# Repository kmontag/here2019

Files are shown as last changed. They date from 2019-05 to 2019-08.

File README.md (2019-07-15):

## Usage

See `featherstream/README.md` and `kontrol/README.md` for usage
overviews of the two main devices.

## Assembly

In addition to the build instructions in `featherstream/README.md` and
`kontrol/README.md`:
  
### DotStar strip

- Compile and print `things/dot_star_endcap.scad`.
- Cut the strip (https://www.adafruit.com/product/2237) to
  the desired number of LEDs along the midpoint of the metal contacts.
- Input side:
  - Run the female end of a 4-wire cable set
    (https://www.adafruit.com/product/744) through the large endcap
    fitting, with the free wire ends coming out of the larger end.
  - Run the wires through the 4 holes in the smaller endcap
    fitting. Check your strip to see the positions of the DI/CI
    contacts, and order the wires such that:
    - Red goes to VOC (+5V)
    - White goes to CI
    - Yellow goes to DI
    - Black goes to GND
  - Solder the wires to the contacts
  - Test the connection by connecting to an assembled feather
  - Put some hot glue or superglue onto the soldered connections for
    extra security.
  - Slide the smaller endcap over the strip, and place an M3 nut
    (https://www.amazon.com/dp/B07JD4ZLFT/) into the receptacle.
  - Put some hot glue or superglue on the outside of the endcap where
    the wires enter.
  - Wrap a bunch of electric tape around the 4-wire cable, between the
    large endcap and the strip. The goal is to reduce strain on the
    soldered connections once the endcap is fastened, so position it
    such that it forces a little bit of slack in the wires when the
    large endcap slides all the way up.
  - Slide the large endcap over the small one, and screw an M3 screw
    (https://www.amazon.com/dp/B01LZYC586/) through the hole, into the
    nut, and down far enough that it presses agains the strip pretty
    hard. The goal is to hold the endcap in place without placing
    strain on the soldered connections.
- Output side:
  - If chaining strips together, this is the same as the input side
    except:
    - Use the male side of the 4-wire cable instead of the female.
    - Make sure you place the over-screw onto the 4-wire cable before
      soldering.
    - Make sure you're soldering to the CO/DO side of the contacts (not CI/DI).
  - If not chaning strips together, you can just seal this off with
    the smaller endcap piece or some shrink wrap / tape.
    
## Development - running a local `featherstreamer` server

`featherstreamer` is what the Pis run to serve pixels to feathers. There are two components:

### `featherstreamer`

This is the main data server. Before running it:

- Place any video files you want to stream in
  `kontrol/media-src/`. These can be anything readable by `ffmpeg`.
- Run `make media` to compile the files into raw pixel data that can
  be streamed without processing overhead. The built files live in
  `kontrol/media-build/`.
- Run `make` in `kontrol/`.

To run the program, in `kontrol/featherstreamer`:

``` bash
npm start
```

You can also use `npm run start-dev` during development, to pick up
changes to source files automatically.

To get a Feather to see your local `featherstreamer` server, you'll
need to make compile-time changes. In your `secrets.h`, place the
following:

``` c++
#define SECRET_PAIRED_SSID "Your home SSID"
#define SECRET_PAIRED_PASSPHRASE "Your WiFi password"
#define SECRET_SERVER_IP IPAddress(192, 168, 0, 1) // Or whatever your computer's local IP address is
```

And then compile and upload to your Feather.

### `featherstreamer-web`

This is the web interface that's normally accessible at
http://192.168.8.1 on a Feather's hosted network. It shows details
about connected devices, and allows you to simulate interactions with
the hardware.

Before starting, run `make` in `kontrol/`. Then start the server with
`npm start` in `kontrol/featherstreamer-web`. The page should open
automatically in your browser; if not, it's accessible at
http://localhost:3000.

Note the UI won't be functional unless the `featherstreamer` server is
also running locally.

## Development dependencies

- PlatformIO for building the feather software: `brew install platformio`
- OpenSCAD for building 3D-printable objects: `brew cask install openscad`
- Ansible for configuring a Pi: `brew install ansible`
- Node/NPM for running the `featherstreamer` server (the thing the Pi
  uses to stream video) locally

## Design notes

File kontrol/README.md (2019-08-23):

This directory contains config and software for a Pi Zero W to:
- run a `featherstreamer` server (and web UI) for `featherstream`
  devices to connect to
- host a local WiFi access point, and connect to (or host) a "master"
  access point when in slave (or master) mode

### Usage overview

This device has an on/off switch, a USB port, an SD card slot, and a
rotary encoder.

The USB port is used to charge the battery (and can power the device
at the same time).

The SD card slot holds the card that runs the Pi.

The on/off switch is an on/off switch.

The rotary encoder is the main controller for the device. Any
contiguous turn in one direcion is processed as a single clockwise or
counter-clockwise "step" - the notches in the encoder don't really
matter. Turn it to cycle through videos. Press it (without turning it)
to toggle connected LEDs on or off.

To change modes, press and hold then encoder for more than 1s, then release it and quickly press it one or more times to select the mode:

- 1 click for isolated mode
- 2 clicks for slave mode
- 3 clicks for master mode
- 4 clicks for pairing mode

Once the device is booted up, you should be able to see a WiFi network
called `featherstreamer-[something]`. That's your device's personal
access point. By default, the password for this network (and all
others) is `feath3rstr`. The device normally lives at
http://192.168.8.1, or http://192.168.9.1 when in master mode.

### Runtime configuration

Connect to the pi's access point and go to http://192.168.8.1 (or
http://192.168.9.1 if the device is in `master` mode) to see a
configuration UI. 

Once a feather is connected, you'll be able to set the channel that
should be streamed to it, the brightness, and the persistent color of
its offline animation.

You can also see some debug info about the device, and simulate
interactions with the rotary encoder.

### Assembly

- First, run the software setup instructions below and make sure your
  unmodified Pi Zero W (https://www.adafruit.com/product/3400) is
  working. During setup, you can power it from the USB port farthest
  from the SD card.
- Get a rotary encoder (https://www.adafruit.com/product/377) and
  solder a short wire between one of the push-switch pins (i.e. either
  pin on the side with two pins) and the middle (common) pin on the
  other side. This allows us to share the ground connection for the
  rotary encoder and the push button.
- Solder a chunk of headers "upside down" (i.e. with the plastic nub
  on the bottom of the chip) to the last 4 pins (i.e. on the side
  furthest from the SD card) of the outer row of the Pi. These pins,
  in order moving away from the SD card, are Ground, GPIO 16, GPIO 20,
  and GPIO 21. Solder ~5cm wires to all of the pins, and slide shrink
  wrap down to secure the connections.
- Solder the wires from the headers to these pins on the rotary encoder:
  - Ground (innermost pin with headers) to Common (middle pin on the encoder side)
  - GPIO16 to rotary pin B (right pin on the encoder side)
  - GPIO20 to rotary pin A (left pin on the encoder side)
  - GPIO21 to the remaining push switch pin
  Make sure to secure the connections with shrink wrap.
- Solder a SPDT slide switch (https://www.adafruit.com/product/805) to
  the Vs, EN, and GND pins of a PowerBoost 1000 charger
  (https://www.adafruit.com/product/2465).
- Solder a 2-pin chunk of headers to the G and 5V pins on the
  PowerBoost. Orient the headers upside-down as with the Pi.
- Solder another 2-pin chunk of headers (again upside-down) to the 2nd
  and 3rd pins on the outer row of the Pi. These are 5V and G,
  respectively.
- Solder ~3cm wires to connect the +5V and G pins of the PowerBoost to
  the Pi.
- Solder a ~1kOhm resistor in series with one leg of an LED, as
  described in the featherstream assembly instructions.
- Cover the resistor legs with shrink wrap. Solder the positive end to
  the Pi's GPIO11 (12th pin on the inner row as you move away from the
  SD card) and G (easiest option is the 13th pin on the inner row as
  you move away from the SD card). Bend the LED legs so it lays across
  the Pi and reaches near the USB ports.
- Connect a 2000mAh LiPo battery
  (https://www.adafruit.com/product/2011) to the PowerBoost.  Do this
  **before** plugging into the PowerBoost's USB port, otherwise you
  may damage the board.
- Plug USB power into the PowerBoost (make sure you're not also
  plugged into the Pi's onboard USB power port). You should see an
  orange light to indicate the battery is charging. If the switch is
  in the ON position, you'll also see a blue light to indicate that
  power is being provided at the 5V pin.
- Test your circuit. With the PowerBoost plugged in and/or the battery
  charged, flip the switch on. You should see:
  - the green onboard LED light up immediately
  - after a few minutes, the installed LED blinking once every ~3s to
    indicate that the server has started and is running in isolated
    mode
    
  To test that the rotary encoder is properly connected, turn it two
  clicks (not rotary notches - see above) while pressing it to place
  the device in slave mode. The LED should then start blinking twice
  every 3s, instead of once.

- Print `../things/pi_box.scad` and put everything inside. The easiest
  order to place things is probaby:
  - PowerBoost placed against the wall opposite the `HERE` text, with
    its switch seated in the small hole and its USB port accessible
    through the back wall. If you want, you can use an M2.5 screw/nut
    to hold the chip in place - seat the nut behind the little post
    with a hole in it near the back of the chip, and run the screw
    through the nearby hole in the chip and into the nut. This isn't
    strictly necessary, but will make it easier to maintain the right
    position while putting the lid on the box.
    
    Note you should leave the battery attached to the PowerBoost - the
    wires should run under the board and behind it, so you can drop
    the battery into the other side of the box once everything else is
    in place.
  - Pi placed in its seat in the middle of the box. The SD card needs
    to be removed before you put the Pi in. It should sit so that the
    USB ports are flush with the top of the box.
  - Rotary encoder placed through the hole opposite the PowerBoost USB
    port, with the square base rotated so that it sits neatly on the
    nearby shelf (i.e. so the soldered pins are on the sides of the
    box, not the top and bottom). **Make sure you put the washer on
    before pushing the encoder through the hole.**
    
    This part can be tricky, be careful not to break any connections -
    if everything is well-soldered and supported with shrink wrap, it
    should be pretty stable. Once the encoder is propertly seated,
    there shouldn't be much strain on any of the soldered connections.
  - Battery placed in the remaining space near the wall with the
    `HERE` text.
- Secure the rotary encoder with the nut that came with it, and attach
  the plastic cap.
- Put the SD card back in the Pi through the box wall and test the
  circuit again to make sure everything's still intact after
  insertion.
- Place M3 nuts (https://www.amazon.com/dp/B07JD4ZLFT) in the two
  holders on the box lid.
- Place the lid and secure it with M3 screws
  (https://www.amazon.com/dp/B01LZYC586).
    
### Media setup

Push videos to the device using `make deploy-media` while connected to
the device's access point.

Config for your lights should get added to `frameplayer.conf.js` in
this directory. Each `featherstream` device receives pixel data for
one channel (you can configure this in the Pi's web UI). For each of
your `featherstream` devices, add a channel with a descriptive name to
`frameplayer.conf.js`, set a height and width to scale video files
before sampling pixels, and then provide a list of pixels (as x/y
coordinates) to sample. Data from these pixels will get sent (in this
order) to your LED strip(s).

Commit any changes to `frameplayer.conf.js`, so that when you're
receiving data from someone else in master mode, you'll get correctly
positioned pixel data on your setup.

### Setup from a distributed image

If you won't be doing any development, you can just burn the image to
an SD card and boot the pi - everything is already installed.

Then put the device into pairing mode (four clockwise clicks while
pressing the rotary encoder), put one or more feathers into pairing
mode (flip the switch repeatedly at boot), and wait for the light on
the feathers to start blinking quickly.

Optionally, in the `boot` volume that mounts when you insert the SD
card into your laptop:

- edit the `reset` file with a custom SSID for your device.
- create a file called `wpa_supplicant.conf` (see the example in this
  directory) containing your home WiFi credentials, to make the device
  connect to your network when it's in `master` or `pairing` mode.

These optional steps can be performed at any time.

### From-scratch Pi setup

- Download the latest Raspbian lite:
  <https://www.raspberrypi.org/downloads/raspbian/>.

- Install onto SD card with Etcher or similar:
  <https://www.raspberrypi.org/documentation/installation/installing-images/README.md>.

- Mount the `boot` partition (i.e. just reinsert the drive) and
  perform preliminary setup:
  
``` shell
$ make boot
```

- Put the SD card into the Pi and boot.

- If you want, test SSH (default password is `raspberry`):

``` shell
$ ssh -o StrictHostKeyChecking=no -o GlobalKnownHostsFile=/dev/null -o UserKnownHostsFile=/dev/null pi@raspberrypi.local
```

- Perform initial hostname/credentials setup. This will also generate
  an SSH key pair in [`ansible/local`](ansible/local) if necessary,
  which will be shared for all future devices. Ansible must be
  installed.

``` shell
$ make bootstrap
```

- Perform all additional provisioning to set up the node. Add the
  outputted hostname from the previous step to
  `ansible/inventory/hosts.local` (create the file if it doesn't
  exist), comment out any hosts you don't want to set up, and run:
  
``` shell
$ make setup
```

- If you want to create an image for distribution, run (using your
  hostname from above):

``` shell
$ PI=featherstreamer-foo.local make prepare
```

  This will remove all sensitive info (i.e. WiFi credentials) from the
  Pi, and place a blank file at `/boot/reset` to trigger a new
  hostname/AP name being set on the next boot.
  
  Before proceeding, SSH into the pi and run `sudo fdisk -u -l`,
  taking note of the end sector of the final `mmcblk0p3` partition.
  
  You can now shut down the Pi and remove its SD card, and use it to
  make an image which will generate a unique AP name every time it's
  installed. To generate the image, use:
  
  ```bash
  dd if=/dev/{ SD card device name } of=/path/to/img/file.img count={ end sector from above + 1 }
  ```
  
  See
  https://serverfault.com/questions/446529/create-image-of-a-usb-drive-without-unallocated-partition
  for more info.

### SSH

It's generally easiest to interact with the Pi over SSH. Probably the
cleanest way to do this is to connect to the pi's hosted access point,
and then log in using `ssh pi@192.168.8.1` (or `ssh pi@192.168.9.1` if
the device is in master mode). The default password is `feath4str`.

If you place a `wpa_supplicant.conf` file in the boot partition (see
the example file in this directory), you can also interact with the Pi
over your home network. The Pi will connect to your home network in
`pairing`, `master`, and `default` network modes. The first two always
correspond to the `pairing` and `master` application modes. If you're
using the development config (which is the case if you set things up
from scratch using ansible), the `isolated` application mode will also
correspond to the `default` mode. (Note the production config uses the
`slave` networking mode while in the `isolated` application mode, to
make it faster to switch over to the `slave` application mode when
requested).

If the Pi is connected to your local network, you can probably find it
at `ssh pi@[access point name].local` (since the access point name is
the same as the pi's hostname).

### Development

If you're able to connect to the Pi via SSH, you can use `make deploy`
and `make deploy-media` to push code changes and media changes,
respectively. You can also still run the ansible playbook using `make
setup`.

Note that the Pi is normally running with its main volumes in
read-only mode, to prevent damage when it's turned off without being
properly shut down. To switch between read-write and read0only mode
during development, use `sudo rw` and `sudo ro`.

### Network overview

Each pi generally runs as both an access point and a WiFi client
simultaneously. This is accomplished via a virtual device (`ap0`)
which is created in addition to the system's default wireless device
(`wlan0`).

In general the pi can be in one of four modes, each of which uses a
different network config: default, pairing, slave, and master.

#### Default

The `ap0` device hosts a network whose SSID is the pi's hostname. Any
paired feathers connect to this network, and the pi streams pixel data
to them. 

The `wlan0` device connects with the standard
`wpa_supplicant.conf`.

#### Pairing mode

The `ap0` device hosts a network called
`featherstreamer-pairing`. When in their own pairing mode, feathers
connect to this network, and use it to retrieve information about the
pi via an HTTP endpoint.

The `wlan0` device connects with the standard
`wpa_supplicant.conf`.

Note that results are unpredictable if multiple nearby pis enter
pairing mode simultaneously; however, the pairing process should
happen relatively rarely.

#### Slave mode

Same as default mode, except the `wlan0` device tries to connect to
the "master" AP `featherstreamer-master`. When a connection is
established, this means another nearby pi has entered master mode; the
slave pi can then forward pixel data from this master to any connected
feathers.

Note that the actual streaming application runs in this mode even when
running in "isolated" mode (i.e. not forwarding data from the master),
so it doesn't have to switch network configs when switching to true
slave mode.

#### Master mode

The `ap0` device hosts the `featherstreamer-master` AP, and broadcasts
pixel data to any connected slaves. Before transitioning to this mode,
the pi notifies any connected feathers that they should disconnect and
start looking for it at the master SSID instead. (The feathers also
try to do this automatically at boot if they're unable to find their
standard AP).

The `wlan0` device connects with the standard
`wpa_supplicant.conf`.

If multiple nearby devices enter master mode, the network will be
segregated depending on which master a slave connects to. A sane state
can be restored by placing all but one of the masters back in a
different mode.

Note that we're somewhat limited in the combinations of network
interfaces which can be created on the pi's single wireless
chip. Check `iw list` for more details about the available options. In
particular, a more natural networking setup for this project might be
to have each pi host an access point (for connected feathers) as well
as join a mesh network with any nearby pi devices for coordinating
lighting masters. This would eliminate the need for live swapping of
network interfaces when a pi wants to present itself as the lighting
master, and make it easier to resolve conflicts when more than one pi
tries to take this position. Unfortunately, a mesh setup (based on
`batman-adv`) requires the use of an ad-hoc network interface, which
cannot be used in tandem with an access point, and which the feathers
apparently aren't able to connect to directly. See, for example,
https://forum.arduino.cc/index.php?topic=431283.msg3073869#msg3073869. Issue
filed at https://github.com/arduino-libraries/WiFi101/issues/273.

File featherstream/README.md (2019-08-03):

Sketch for a WiFi-enabled Feather to interface with a featherstreamer
server.

Inspiration: https://learn.adafruit.com/lightship-led-animation-over-wifi/software

### Usage overview

This device has a USB port, a rocker switch, a cable to connect to a
DotStar LED strip, and a power input.

The USB port is mainly just used to flash the chip, though you can
also use it to power the device and a small number of lights. Don't
push too much power through this, you'll fry the device and possibly
your USB port.

The power input should receive around 3.7-5V DC (don't exceed 5V,
you'll fry the circuit). The easiest way to achieve this is to plug 3
rechargeable AA batteries into the power input. This will power the
chip, and up to about 100 attached LEDs depending on brightness.

The device runs whenever power is connected, so if you want a power
on/off switch, it's best to get a battery pack that has one built in.

When the rocker switch is OFF, the device runs in "offline mode,"
meaning it just shows a simple predefined animation. The animation
color can be configured (persistently) from a `featherstreamer` web
UI, once you pair with a Pi device.

When the rocker switch is ON, the device attempts to connect to a
Pi. There are two possibilities here:

- If the device has not yet been paired, it immediately enters pairing
  mode, meaning it searches for a network called (by default)
  `_featherstreamer-pairing`. This network is hosted by a Pi when it's
  in its own pairing mode. If this network is found, the
  `featherstream` connects and retrieves/persists info that will let
  it connect to this Pi in the future. You'll know the connection is
  successful if the LED starts blinking rapidly - at this point you
  should reboot the device.
  
  Note that if the device is already paired, you can also enter
  pairing mode by flipping the rocker switch rapidly while booting the
  device. This allows you to re-pair with a different Pi.
  
- If the device has been paired, it searches for its Pi, either on the
  master network or on the Pi's "personal" access point. If found, it
  starts pulling pixel data from the Pi.
  
You can usually flip the rocker switch on and off at runtime to change
modes. There's one exception: if you enter pairing mode (e.g. if you
boot the device with the switch on when it isn't paired), you'll have
to reboot with the switch off in order to get back to offline mode.

### Assembly

- Connect to a Feather M0 WiFi w/ PCB antenna
  (https://www.adafruit.com/product/3010) via USB, and upload the
  `featherstream` program (`make upload` from this directory).
- Compile and print `../things/feather_box.scad`.
- Solder wires to the ground and + pins of a 5.5mm x 2.1mm DC female
  jack, e.g. https://www.amazon.com/dp/B07C4TG74T/.
- Run the male side of a 4-wire cable set
  (https://www.adafruit.com/product/744) into the smaller circular
  hole on the box. Once soldered, you won't be able to remove this
  cable, so make sure to place the over-screw on the cable before
  running it through. If you want, use a big wire stripper or knife to
  strip a bit of the black coating off the back; this will give you
  more room to work with the wires.
- Solder wires to both pins of a rocker switch,
  e.g. https://www.amazon.com/dp/B0725Z6FR7/, and snap it into the
  hole on the long side of the box. Orient it such that the open
  position is closer the end of the box with circular cutouts. (You
  may want to snap it in and out while connecting parts of the
  circuit - just make sure the wires are running through this hole
  from the outside before you solder anything.)
- Splice together the red wire from the 4-wire cable and the + wire
  from the DC jack, and run a single wire out from the splice
  (i.e. form a "Y").
- Splice together the black wire from the 4-wire cable, the ground
  wire from the DC jack, and one of the wires from the rocker switch,
  and run a single wire out from the splice.
- Bend either leg of a simple LED
  (e.g. https://www.amazon.com/dp/B073QMYKDM/) and one side of a
  ~1kOhm resistor (e.g. https://www.amazon.com/dp/B0185FIJ9A/) into
  hooks. Hook them together, and solder them in place to "extend" the
  LED leg with the resistor. You might want to trim them a bit so you
  end up with two legs of approximately the same length coming from
  the LED.
- Break off a chunk of 6 header pins from the headers that came with
  your feather, and solder it between the BAT pin and pin 11. Then
  solder:
  - The yellow wire from the 4-wire cable to pin 11 (this will
    connect with DI on the strip)
  - The white wire from the 4-wire cable to pin 13 (this will
    connect with CI on the strip)
  - To the BAT pin:
    - The spliced +/red wire, AND
    - the + terminal of a 1000uf 6.3v capacitor
      (https://www.amazon.com/dp/B01DYJEHZ2/)
      Be sure to cover the capacitor leg with heat shrink wrap before
      soldering.
- Break off a chunk of 5 header pins, and solder it between A3 and
  G. Then solder:
  - The remaining wire from the rocker switch to A3.
  - The positive terminal of the LED/resistor combo
    to A1. Cover the leg with shrink wrap before soldering.
  - To the fifth pin (again make sure to cover legs with shrink wrap):
    - The spliced ground wire
    - the ground terminal of the LED/resistor combo
    - the gorund terminal of the capacitor
- Put the DC jack through the remaining hole in the box, and use the
  nut to fasten it into place from the outside. Rotate the jack so
  that the soldered wires are at the highest point, otherwise the
  feather won't fit.
- Stuff the feather into the box and onto the feather-shaped platform.
- Place M3 nuts (https://www.amazon.com/dp/B07JD4ZLFT/) into the
  holders in the box lid, and attach the lid using M3 screws
  (https://www.amazon.com/dp/B01LZYC586/).

### Setup

Create `include/secrets.local.h`, and optionally override values from
`include/secrets.h` to provide custom configuration. For example, if
you're running a `featherstreamer` server locally and your machine has
IP `192.168.0.10`:

``` c++
// include/secrets.local.h

#define SECRET_PAIRED_SSID "my-ssid"
#define SECRET_PAIRED_PASSPHRASE "my-passphrase"
#define SECRET_PAIRED_SERVER_IP IPAddress(192, 168, 0, 10)
```

By default, `include/secrets.h` provides credentials that match the
default `featherstreamer` config. In general, to interface with a
network of `featherstreamer`s, all `featherstreamer` devices need to
have the same master/pairing credentials, and the same password but
unique SSIDs for their "default" AP.

### Detailed behavior

There are three operating modes.

#### Pairing mode

The device looks for a network and a featherstreamer host based on the
provided `SECRET_PAIRING_*` secrets. If it finds one, it retrieves the
SSID and saves it to flash storage for future use, overwriting any
existing config. The change will take effect when the device is rebooted.

If the device has never been paired before (and if
`SECRET_PAIRED_SSID` was not provided), the device will enter this
mode as soon as the switch is closed (i.e. as soon as you attempt to
enter OPC mode).

If the device is already paired, flip the switch rapidly while booting
to enter it.

Once the device enters this mode, it won't leave until it's rebooted.

LED indicators:

1s on / 1s off -> looking for pairing network

continuous rapid blinks -> cnnected to network and successfully pulled
an SSID from a featherstreamer; device can be rebooted

short blinks with 1s pause in between -> connected to network but
couldn't retrieve an SSID, likely a problem with the featherstreamer

#### OPC mode

This is the mode when the device is paired (i.e. has a stored SSID)
and its switch is closed.

The device continually tries to connect to either the master network,
or to the SSID stored during pairing. In the former case, the device
keeps reconnecting unless it finds a featherstreamer server whose
`/ssid` endpoint matches its paired value. In other words, it
continually tries to connect to its paired featherstreamer, allowing
for the possibility that the paired featherstreamer may currently be
in master mode.

Once connected, the device hits the featherstreamer's device-based OPC
endpoint and continually displays incoming data, using the MAC address
of the onboard WiFi chip to generate a consistent identifier between
boots/flashes. (The pixel channel for a given device ID can be
configured from the featherstreamer web UI.) Sysex messages (OPC
command 255) are also supported. The first two bytes of these commands
should be an unsigned number with the high byte first, representing
the system ID; currently only one system ID is supported:

- SID 6: Set one of the colors of the offline animation, and save this
  value to flash storage. The message data should be 6 bytes - 2 for
  the system ID, 1 for the index (between 0 and 2 inclusive), and 1
  each for the R, G, and B values respectively.

#### Offline mode

This is the mode when the device is paired and its switch is open.

In offline mode, a generic animation is shown, optionally using up to
3 colors set by OPC sysex command as described above.

### Building and uploading

See the `Makefile`.

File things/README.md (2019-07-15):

Chip models sourced from:

- https://grabcad.com/library/adafruit-powerboost-1000c-3
- https://grabcad.com/library/raspberry-pi-zero-w-board-1

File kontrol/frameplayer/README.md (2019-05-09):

### frameplayer

1. Sample pixel data at a constant framerate from video files.

2. Load the sampled data into an event emitter, and "play" it back
   however you like by listening to frame events.
   
Sampled data can be persisted to a file for later use in, e.g.
resource-constrained environments.

Might be useful for your [Open Pixel
Control](http://openpixelcontrol.org/) projects.

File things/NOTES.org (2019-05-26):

* Receivers
  - 3-way switch for Off, Built-in, OPC lighting states
  - 8-way or so switch for channel (interior?)
  - Pairing with controller

* Kontrollers
  Mesh network. Possible approaches:
  - https://hackaday.com/2012/11/14/mesh-networking-with-multiple-raspberry-pi-boards/
  - https://github.com/tomeshnet/prototype-cjdns-pi
  - https://github.com/suiluj/pi-adhoc-mqtt-cluster

  Pi automated setup, see
  https://www.raspberrypi.org/forums/viewtopic.php?t=190921,
  https://www.pibakery.org/

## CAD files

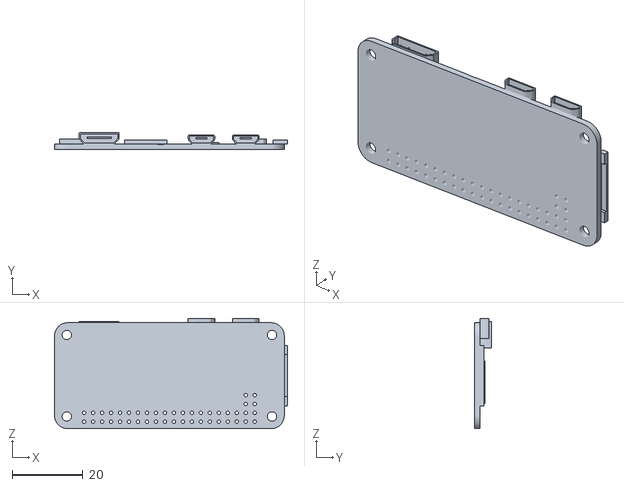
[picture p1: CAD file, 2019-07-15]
things/RaspberryPiZeroW.STL
65.9 x 4.80 x 31.2

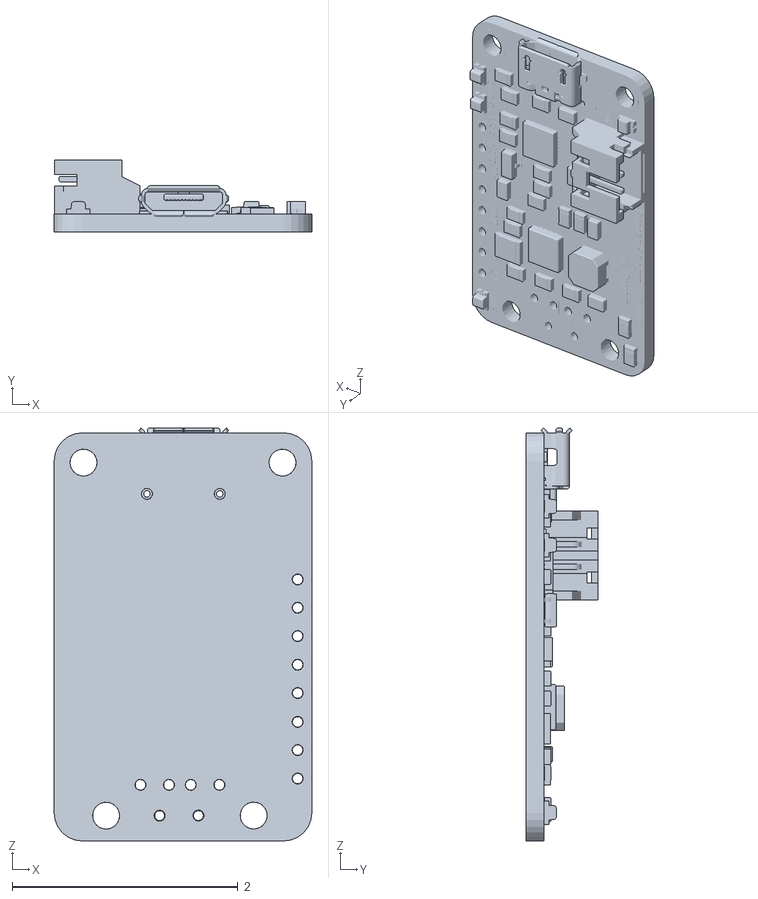
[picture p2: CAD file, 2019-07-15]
things/SuperBoost1000C.stl
2.29 x 0.639 x 3.66

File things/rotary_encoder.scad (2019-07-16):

include <BOSL/constants.scad>
use <BOSL/shapes.scad>
use <BOSL/transforms.scad>
use <math.scad>

boxSize = [13.2, 6.5, 12.5];
pinsMaskSize = [1.5, 6, 12.5];

module rotaryEncoder(slop = PRINTER_SLOP) {
  slop(size=boxSize, slop=slop) cuboid(size=boxSize, p1=[0, 0, 0]);
  for (i = [-1, 1]) {
    back(boxSize[1]) left(pinsMaskSize[0] / 2) right((i + 1) * boxSize[0] / 2)
      slop(size=pinsMaskSize, slop=slop) cuboid(size=pinsMaskSize, p1=[0, 0, 0]);
    
  }

  knobDiameter = 7;
  knobHeight = 15;
  right(boxSize[0] / 2) up(boxSize[2] / 2)
    yflip()
    slop(size=[knobDiameter, knobHeight, knobDiameter])
    ycyl(d=knobDiameter, align=ALIGN_POS, h=knobHeight);
}

function rotaryEncoderBoxSize() = boxSize;

rotaryEncoder();

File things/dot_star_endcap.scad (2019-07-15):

include <MCAD/boxes.scad>
include <MCAD/triangles.scad>

// smaller for higher-res curves
$fs = 0.1;
epsilon = 0.01;

debug = false;

stripWidth = 12;
stripHeight = 4.5;

coneLockHoleRadius = 1.5; // M3 screw
coneLockBoltWidth = 5.5 + 0.2; // Expected + real-world adjustment

lockPadHeight = 1;

leeway = 0.3;

solderDepth = 7;
solderWindowDepth = 3.7;
wallWidth = 0.9;
capDepth = solderDepth + 2 * wallWidth + coneLockBoltWidth + 2 * leeway;
capWidth = stripWidth + 2 * wallWidth;
capHeight = stripHeight + 2 * wallWidth;

radius = 0.2;

numPins = 4;
pinRadius = 1.1;

slideLeeway = 0.35;

conePlacement = debug ? 0 : capWidth + wallWidth * 2 + 5;
coneAlpha = debug ? 0.8 : 1;

coneCubeWallWidth = wallWidth;
wireRadius = 2.5;
wireClench = 0.08;
wireClenchLength = 5;
coneLength = 33;
coneTipLength = 8;
coneMaxRadius = (2 * slideLeeway + 2 * coneCubeWallWidth + capHeight) / 2;

coneCubeDepth = capDepth;
coneCubeOuterWidth = capWidth + 2 * slideLeeway + 2 * coneCubeWallWidth;


// main endcap
translate([0, 0, debug ? capDepth : 0]) mirror([0, 0, debug ? 1 : 0]) union() {

  difference() {
    union() {
      smoothingInset = 0.15;
      difference() {
        translate([capWidth / 2, capHeight / 2, capDepth / 2]) {
          roundedBox([capWidth, capHeight, capDepth], radius, false);
        }

        // hole for lock bolt, leave a partial edge at the top so we
        // can keep it smooth after adding the hexagon shape
        translate([0, -capHeight / 2, 0]) {
          translate([wallWidth + stripWidth / 2, wallWidth + stripHeight / 2, 2 * wallWidth + solderDepth + coneLockBoltWidth / 2 + leeway - radius / 2]) {
            cube([coneLockBoltWidth + 2 * leeway, capHeight + 0.1, coneLockBoltWidth + 2 * leeway - radius], true);
          }
          translate([wallWidth + stripWidth / 2, wallWidth + stripHeight / 2, 2 * wallWidth + solderDepth + coneLockBoltWidth / 2 + leeway + 0.1]) {
            cube([coneLockBoltWidth / 2 + leeway + 2 * smoothingInset, capHeight + 0.1, coneLockBoltWidth + 2 * leeway + 0.2], true);
          }
        }

        // hole over soldered parts for gluing
        translate([capWidth / 2, capHeight / 2, 2 * wallWidth]) {
          difference() {
            rotate([90, 0, 0]) {
              cylinder(capHeight + 2 * epsilon, solderWindowDepth, solderWindowDepth, true);
            }
            translate([-capWidth / 2, -capHeight / 2, -solderWindowDepth]) {
              cube([capWidth, capHeight, solderWindowDepth], false);
            }
          }
        }
      }


      // hexagonal lock bolt shape
      translate([0, -capHeight / 2, 0]) {
        difference() {
          union() {
            for (i = [0:3]) {
              translate([capWidth / 2, 0, 2 * wallWidth + solderDepth + (coneLockBoltWidth + 2 * leeway) / 2]) {
                mirror([0, 0, i % 2]) mirror([floor(i / 2), 0, 0]) {

                  translate([-(coneLockBoltWidth + 2 * leeway) / 2, capHeight, (coneLockBoltWidth + 2 * leeway) / 2]) rotate([90, 90, 0]) {
                    triangle((coneLockBoltWidth + 2 * leeway) / 4, (coneLockBoltWidth + 2 * leeway) / 2, capHeight / 2);
                  }
                }
              }
            }
          }

          // smooth top edge
          translate([capWidth / 2, capHeight / 2, capDepth]) {
            cube([(coneLockBoltWidth + 2 * leeway), capHeight + 0.1, 2 * radius], true);
            cube([coneLockBoltWidth / 2 + leeway + 2 * smoothingInset, capHeight + 0.1, coneLockBoltWidth], true);
          }
        }
      }
    }

    // main center
    translate([wallWidth, wallWidth, wallWidth]) {
      cube([stripWidth, stripHeight, (capDepth - wallWidth) + 0.1]);
    }

    // pins
    translate([wallWidth, wallWidth + stripHeight / 2, wallWidth / 2]) {
      for (i = [1:numPins]) {
        translate([(i * stripWidth / numPins) - (stripWidth / numPins / 2), 0, 0]) {
          cylinder(wallWidth + 0.1, pinRadius, pinRadius, true);
        }
      }
    }

  }

  // locking pad below screw, for additional compression
  translate([capWidth / 2, capHeight - (lockPadHeight / 2) - wallWidth, capDepth - (coneLockBoltWidth / 2) - leeway]) {
    rotate([90, 0, 0]) {
      cylinder(lockPadHeight, coneLockBoltWidth / 2, coneLockBoltWidth / 2 - lockPadHeight, true);
    }
  }
}

// additional fitting over wire
color("blue", coneAlpha) translate([conePlacement + (capWidth) / 2, -coneCubeWallWidth - slideLeeway, 0]) {

  mirror([0, 0, 1]) translate([0, coneMaxRadius, -coneLength - coneCubeDepth]) {

    difference() {

      // main cone shape
      union() {
        translate([0, 0, coneTipLength / 2]) {
          cylinder(coneTipLength, wireRadius + wallWidth + leeway, wireRadius + wallWidth + leeway, true);
        }
        hull() {
          translate([0, 0, coneTipLength]) {
            translate([0, 0, (coneLength - coneTipLength) / 2]) cylinder(coneLength - coneTipLength, wireRadius + wallWidth + leeway, coneMaxRadius, true);
          }
          translate([0, 0, coneLength + coneCubeDepth / 2]) {
            roundedBox([coneCubeOuterWidth, coneMaxRadius * 2, coneCubeDepth], radius, false);
          }
        }
      }

      // carve out inner main cone shape. leaves extra width on the
      // cube wall, we'll carve this out below and create a ridge.
      union() {
        translate([0, 0, wireClenchLength / 2]) {
          cylinder(wireClenchLength + 0.1, wireRadius + leeway, wireRadius + leeway - wireClench, true);
        }
        translate([0, 0, wireClenchLength + (coneTipLength - wireClenchLength) / 2]) {
          cylinder(coneTipLength - wireClenchLength + 0.1, wireRadius + leeway - wireClench, wireRadius + leeway - wireClench, true);
        }

        hull() {
          translate([0, 0, coneTipLength]) {
            translate([0, 0, (coneLength - coneTipLength) / 2]) {
              cylinder(coneLength - coneTipLength, wireRadius + leeway - wireClench, coneMaxRadius - coneCubeWallWidth - slideLeeway, true);
            }
          }

          translate([0, 0, coneLength + coneCubeDepth / 2]) {
            cube([capWidth, (coneMaxRadius - coneCubeWallWidth - slideLeeway) * 2, coneCubeDepth + 0.1], true);
          }
        }
      }

      // hole for lock
      translate([0, -coneMaxRadius, coneLength + wallWidth + solderDepth + wallWidth + (coneLockBoltWidth + 2 * leeway) / 2]) {
        rotate([90, 0, 0]) {
          cylinder(coneMaxRadius * 2 + 0.1, coneLockHoleRadius + leeway, coneLockHoleRadius + leeway, true);
        }
      }

      // carve out additional cube area, create ridge to catch main
      // endcap.
      translate([0, 0, coneLength]) {
        hull() {
          slopeHeight = 0.5;
          translate([0, 0, 0.01]) {
            cube([capWidth, (coneMaxRadius - coneCubeWallWidth - slideLeeway) * 2, 0.02], true);
          }
          translate([0, 0, slopeHeight + (coneCubeDepth - slopeHeight) / 2 + 0.1]) {
            cube([capWidth + 2 * slideLeeway + 0.1, capHeight + 2 * slideLeeway + 0.1, coneCubeDepth - slopeHeight + 0.2], true);
          }
        }
      }

    }

  }
}

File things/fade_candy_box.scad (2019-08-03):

include <BOSL/constants.scad>
use <BOSL/shapes.scad>
use <BOSL/transforms.scad>
use <math.scad>
use <nut_holder.scad>
use <outer_box.scad>

$fn=30;

wallWidth = 2;
fillet = 2;

pcbHeight = 1.2;

cableDiameter = 4.5 + 2 * PRINTER_SLOP;
cableGapLeeway = 1;
cableGapWidth = cableDiameter + cableGapLeeway;
cableGapPinch = 0.2;
cableExtraInset = 7;
separatorWallHeight = 4 * cableDiameter;
numOutputs = 8;

// Space behind the chip so the pins aren't pressing right up against the wall.
pinLeeway = 1;

nutVertexDistance = 6.5 + PRINTER_SLOP;
nutEdgeDistance = 5.65 + PRINTER_SLOP;
nutDepth = 3;
screwDiameter = 3 + PRINTER_SLOP;
nutHolderWallWidth = 1;

fadeCandySideSpacing = 12;

fadeCandySize = [20 + 2 * PRINTER_SLOP, 38 + 2 * PRINTER_SLOP, pcbHeight + 2 * PRINTER_SLOP];
usbPortSize = [7.3, 9.85, 4];
usbPortStartX = 7;

textInlay = 1;

lidInsetWidth = 1;
lidInsetDepth = 1;

size = [
  fadeCandySize[2] + usbPortSize[2] + 2 * (fadeCandySideSpacing + cableExtraInset + wallWidth + cableGapWidth),
  fadeCandySize[1] + pinLeeway + 2 * PRINTER_SLOP,
  fadeCandySize[0] + 3 * PRINTER_SLOP + lidInsetDepth,
];


module circuit() {
  // Fadecandy
  right((size[0] + usbPortSize[2]) / 2 + fadeCandySize[2]) yrot(-90) right(PRINTER_SLOP) union() {
    // PCB
    slop(size=fadeCandySize)
      color("blue") cuboid(size=fadeCandySize, p1=[0, 0, 0]);

    // USB port with overhang for an insert
    usbOverhang = 5;
    right(usbPortStartX)
      up(pcbHeight) {
      forward(usbOverhang)
      slop(size=usbPortSize)
      color("gold") cuboid(size=usbPortSize + [0, usbOverhang, 0], p1=[0, 0, 0]);

      // Space for clips on the sdies
      for (i = [0, 1]) {
        clipDim = 2;
        right(i * usbPortSize[0])
          color("white") cuboid([clipDim, usbPortSize[1] + PRINTER_SLOP, clipDim], p1=[(i - 1) * clipDim, PRINTER_SLOP, 0]);

      }
    }

    // Surface components (where relevant).
    color("green", alpha=0.5)
      up(pcbHeight)
      back(2 - PRINTER_SLOP)
      cuboid(size=[usbPortStartX, 12, 2], p1=[0, 0, 0]);
  }

  // Data cables and markers
  color("gray") union() {
    for (side = [0: 1]) {
      for (col = [0 : 1]) {
        for (row = [0 : 1]) {
          up(separatorWallHeight * (row / 2 + 1 / 4) + cableDiameter / 2)
            back(cableGapWidth * (1 + col * 2) + col * wallWidth)
            right(PRINTER_SLOP + side * (size[0] + wallWidth))
            xcyl(d=cableDiameter, l=wallWidth * 2, align=V_ALLNEG);

          left(wallWidth - textInlay)
            up(cableDiameter * (1 + 2 * row))
            back(cableDiameter * (2.5 + 3 * col - side * 0.6) - 1)
            right((size[0] + wallWidth) * side)
            xrot(90)
            yrot(-90)
            mirror([0, 0, side])
            mirror([side, 0, 0])
            linear_extrude(height = textInlay + wallWidth)
            text(str(side == 0 ?
                     3 - (2 * row + col) :
                     8 - (1 - col) - row * 2 - 1),
                 valign="center", halign="left", size=cableDiameter, font="Liberation Sans");
        }
      }
    }
  }

  // Here
  color("green")
    right(size[0] / 2)
    up(wallWidth)
    back(size[1] - textInlay + wallWidth)
    zrot(180)
    xrot(90)
    linear_extrude(height=textInlay + wallWidth)
    text("HERE", font="Helvetica", size=16, halign="center", valign="bottom");

}

module lid(mask=false) {
  difference() {
    union() {
      outerBoxLid(
        wallWidth=wallWidth,
        size=size,
        fillet=fillet,
        insetWidth=lidInsetWidth,
        insetDepth=lidInsetDepth
      );

      nutHolderPositions = [[PRINTER_SLOP, size[1] - PRINTER_SLOP - wallWidth], [size[0] - PRINTER_SLOP - 2 * nutHolderWallWidth - nutDepth, size[1] - PRINTER_SLOP - wallWidth]];
      for (i = [0: 1]) {
        up(size[2]) {
          down(lidInsetDepth)
            right(nutHolderPositions[i][0])
            back(nutHolderPositions[i][1])
            yscale(-1)
            zflip() {

            if (mask) {
              nutHolderMask(
                nutVertexDistance=nutVertexDistance,
                nutEdgeDistance=nutEdgeDistance,
                screwDiameter=screwDiameter,
                l=(size[1] / 2)
              );
            } else {
              nutHolder(
                nutVertexDistance=nutVertexDistance,
                nutEdgeDistance=nutEdgeDistance,
                nutDepth=nutDepth,

                screwDiameter=screwDiameter,

                wallWidthLeft=nutHolderWallWidth,
                wallWidthFront=wallWidth,
                wallWidthRight=nutHolderWallWidth,
                wallWidthTop=wallWidth
              );
            }
          }
        }
      }

      // Hold the FadeCandy in place vertically
      extraSpace = 0.3 + PRINTER_SLOP;
      right(size[0] / 2 - wallWidth / 2)
        back(size[1] / 2)
        up(fadeCandySize[0] + extraSpace)
        cuboid([4 * wallWidth, wallWidth, size[2] - fadeCandySize[0] - extraSpace], p1=[0, 0, 0]);
    }
    color(alpha=0.1) circuit();
  }
}

right(wallWidth) back(wallWidth) up(wallWidth) {

  //circuit();

  // Internals
  difference() {
    union() {
      // Walls holding the FadeCandy in place. These are positioned to
      // avoid bumping into components on the chip surface.
      right(size[0] / 2 - wallWidth) {
        platformWidth = 4 * wallWidth;
        left(pcbHeight + usbPortSize[2])
          cuboid(size=[platformWidth + pcbHeight + usbPortSize[2], usbPortSize[1] * 0.75, usbPortStartX + usbPortSize[0] * 0.75], p1=[0, 0, 0]);
        cuboid(size=[platformWidth, 3, 8], p1=[0, fadeCandySize[1] - 15, 0]);

        cuboid(size=[pcbHeight + 6 * PRINTER_SLOP, pinLeeway, size[2] - 2 * wallWidth], p1=[usbPortSize[2] - PRINTER_SLOP * 2, fadeCandySize[1], 0]);
      }


      // Strain relief channels for cables.
      for (side = [0 : 1]) {
        right(side * size[0]) mirror([side, 0, 0]) union() {
          for (i = [0 : 1]) {
            back(i * (2 * cableGapWidth + wallWidth) - wallWidth) {
              back(3 * cableGapWidth - wallWidth * 2)
                cuboid(size=[cableGapWidth + wallWidth + cableExtraInset, wallWidth, separatorWallHeight],
                       p1=[0, 0, 0]);
              back(wallWidth - PRINTER_SLOP) right(cableGapWidth)
                cuboid(size=[wallWidth, cableGapWidth + cableGapLeeway + PRINTER_SLOP + cableGapPinch, separatorWallHeight], p1=[0, 0, 0]);
            }
          }
        }
      }


    }
    circuit();

    // Make sure we're not running into the lid.
    lid(mask=true);
  }

  // Outer box
  difference() {
    color(alpha=0.1)
      outerBox(
        wallWidth=wallWidth,
        size=size,
        fillet=fillet
      );

    circuit();
    lid(mask=true);
  }

  // Lid
  back(size[1] + 10)
    right(size[0])
    yrot(180)
    down(size[2])
    lid();
}

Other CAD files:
things/feather_box.scad
things/finder_wedge.scad
things/math.scad
things/neo_pixel_endcap.scad
things/nut_holder.scad
things/outer_box.scad
things/pi_box.scad
things/pi_zero_w.scad
things/power_boost_1000c.scad

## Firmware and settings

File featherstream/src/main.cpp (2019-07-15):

// Enable this #define if using Adafruit ATWINC (e.g. Feather M0 WiFi).
// If using Arduino Zero + WiFi Shield 101, comment it out:
#define ADAFRUIT_ATWINC

#include <Arduino.h>
#include <WiFi101.h>

// Store sensitive data in this file.
#include "secrets.h"

#include "FeatherstreamerManager.hpp"
#include "TwinkleAnimation.hpp"
#include "OPCHandler.hpp"
#include "Renderer.hpp"
#include "WiFiHandler.hpp"

#define LED_PIN A1
#define RANDOM_PIN A2
#define SWITCH_PIN A3

void printWiFiStatus();
void printEncryptionType(int thisType);

void blink(uint32_t identifier, uint32_t onDurationMs, uint32_t periodMs, uint32_t offsetMs);
void pairing();

featherstream::FeatherstreamerManager *featherstreamerManager;
featherstream::Renderer *renderer;
featherstream::OPCHandler *opcHandler;
featherstream::TwinkleAnimation *offlineAnimation;
featherstream::WiFiHandler *wiFiHandler;

int lastSwitchState = -1;

void setup() {
  //Initialize serial and wait for port to open:
  Serial.begin(9600);
  // while (!Serial) {
  //   ; // wait for serial port to connect. Needed for native USB port only
  // }

  Serial.println("== featherstream ==");

  pinMode(LED_PIN, OUTPUT);
  pinMode(RANDOM_PIN, INPUT);
  pinMode(SWITCH_PIN, INPUT_PULLUP);

  randomSeed(analogRead(RANDOM_PIN));

#ifdef ADAFRUIT_ATWINC
  WiFi.setPins(8, 7, 4, 2); // Pins for Adafruit ATWINC1500 Feather
#endif

  // check for the presence of the shield:
  if (WiFi.status() == WL_NO_SHIELD) {
    Serial.println("WiFi shield not present");
    // don't continue
    while (true);
  }

  featherstreamerManager = new featherstream::FeatherstreamerManager();
  renderer = new featherstream::Renderer();
  offlineAnimation = new featherstream::TwinkleAnimation(*renderer);
  opcHandler = new featherstream::OPCHandler(*renderer, *offlineAnimation);
  wiFiHandler = new featherstream::WiFiHandler(*featherstreamerManager);

  Serial.print("My name is ");
  Serial.println(opcHandler->getDeviceID());

  // If pairing credentials were provided at compile time, add them
  // here on first boot. Note we can still enter pairing mode later
  // to change them.
#ifdef SECRET_PAIRED_SSID
  if (!wiFiHandler->isPaired()) {
    wiFiHandler->setPairedSSID(SECRET_PAIRED_SSID);
  }
#endif

  renderer->clear();
  Serial.println("Turned off LEDs");

  // Check for more than two clicks of the switch in 500ms to force pairing mode.
  uint32_t pairingPossibleUntil = millis() + 500;
  uint32_t numClicks = 0;

  int buttonState = digitalRead(SWITCH_PIN);

  while(millis() < pairingPossibleUntil) {
    int nextButtonState = digitalRead(SWITCH_PIN);
    if (nextButtonState != buttonState) {
      numClicks++;
    }
  }

  if (numClicks >= 2) {
    // This will run forever, so we'll never enter the main loop.
    pairing();
  }

}

void loop() {
  int switchState = digitalRead(SWITCH_PIN);
  if (switchState != lastSwitchState) {
    Serial.print("Entered switch state ");
    Serial.println(switchState);
    renderer->clear();
  }

  if (switchState == HIGH) {
    blink(1, 100, 3000, 0);
    blink(2, 100, 3000, 300);
    if (opcHandler->isConnected()) {
      opcHandler->disconnect();
    }
    offlineAnimation->loop();
  } else if (!wiFiHandler->isPaired()) {

    // Enter pairing mode, which runs forever.
    pairing();

  } else {

    // While connected, show a slow blink. While not connected, just
    // always keep the LED on.
    bool opcConnected = opcHandler->isConnected();
    if (opcConnected) {
      blink(1, 100, 2000, 0);
    } else {
      blink(1, 100, 100, 0);
    }

    if (wiFiHandler->ensureConnected()) {

      if (!opcConnected) {
        Serial.println("Establishing connection to OPC server.");
        opcConnected = opcHandler->connect(1, wiFiHandler->getServerAddress(), SECRET_SERVER_PORT);
      }

      if (opcConnected) {
        opcConnected = opcHandler->loop();
        if (!opcConnected) {
          renderer->clear();

          Serial.println("Lost connection to OPC server.");
        }
      } else {
        renderer->clear();
        const uint32_t delayMillis = 2000;
        uint32_t delayUntil = millis() + delayMillis;
        while (millis() < delayUntil) {
          for (uint8_t i = 0; i < 3; i++) {
            blink(i, 100, delayMillis, 200 * i);
          }
          delay(40);
        }

        Serial.println("Could not connect to OPC server.");
      }
    } else {
      renderer->clear();

      Serial.println("Could not connect to WiFi.");

      const uint32_t delayMillis = 3000;
      uint32_t delayUntil = millis() + delayMillis;
      while (millis() < delayUntil) {
        for (uint8_t i = 0; i < 5; i++) {
          blink(i, 100, delayMillis, 200 * i);
        }
      }
    }
  }

  lastSwitchState = switchState;
}

/**
 * Connect to the pairing network, try to pull credentials from the
 * featherstreamer server, and serve HTTP requests forever, presenting
 * a minimal UI to change device config.
 */
void pairing() {
  Serial.println("Entered pairing mode");

  // Connect to WiFi
  bool isLit = false;
  while (WiFi.begin(SECRET_PAIRING_SSID, SECRET_PAIRING_PASSPHRASE) != WL_CONNECTED) {
    Serial.print("Trying to connect to SSID ");
    Serial.println(SECRET_PAIRING_SSID);

    isLit = !isLit;
    digitalWrite(LED_PIN, isLit ? HIGH : LOW);

    delay(1000);
  }

  // Try to pull network credentials from the featherstreamer we're connected to.
  const String ssid = featherstreamerManager->getReportedSSID(SECRET_PAIRING_SERVER_IP, SECRET_SERVER_PORT);
  // const char *passphrase = featherstreamerManager->getReportedPassphrase(SECRET_PAIRING_SERVER_IP, SECRET_SERVER_PORT);

  if (ssid.length() > 0) { // && passphrase != NULL) {
    wiFiHandler->setPairedSSID(ssid.c_str());
    Serial.print("Pulled SSID from featherstreamer server: ");
    Serial.println(ssid);

    // Fast blink indicates success.
    while (true) {
      blink(1, 100, 300, 0);
    }
  } else {
    // Slower blink indicates error.
    while(true) {
      blink(1, 100, 1000, 0);
    }
  }
}

/**
 * Call this repeatedly to blink the notification LED at a consistent
 * rate. To get multiple blinks with uneven timing, call blink() for
 * each one with an offset, and pass a unique consistent identifier
 * (can be anything except 0) for each blink in the series.
 */
uint32_t activeBlink = 0;
void blink(uint32_t identifier, uint32_t onDurationMs, uint32_t periodMs, uint32_t offsetMs) {
  uint32_t positionMs = (millis() + offsetMs) % periodMs;
  if (positionMs < onDurationMs) {
    if (activeBlink != identifier) {
      digitalWrite(LED_PIN, HIGH);
      activeBlink = identifier;
    }
  } else {
    if (activeBlink == identifier) {
      digitalWrite(LED_PIN, LOW);
      activeBlink = 0;
    }
  }
}

void printWiFiStatus() {
  // print the SSID of the network you're attached to:
  Serial.print("SSID: ");
  Serial.println(WiFi.SSID());

  // print your WiFi shield's IP address:
  IPAddress ip = WiFi.localIP();
  Serial.print("IP Address: ");
  Serial.println(ip);

  // print the received signal strength:
  long rssi = WiFi.RSSI();
  Serial.print("signal strength (RSSI):");
  Serial.print(rssi);
  Serial.println(" dBm");
  // print where to go in a browser:
  Serial.print("To see this page in action, open a browser to http://");
  Serial.println(ip);

}

void printEncryptionType(int thisType) {
  // read the encryption type and print out the name:
  switch (thisType) {
  case ENC_TYPE_WEP:
    Serial.println("WEP");
    break;
  case ENC_TYPE_TKIP:
    Serial.println("WPA");
    break;
  case ENC_TYPE_CCMP:
    Serial.println("WPA2");
    break;
  case ENC_TYPE_NONE:
    Serial.println("None");
    break;
  case ENC_TYPE_AUTO:
    Serial.println("Auto");
    break;
  }
}

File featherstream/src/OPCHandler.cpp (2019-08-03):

#include "OPCHandler.hpp"
#include "Renderer.hpp"

#include <Arduino.h>
#include <WiFi101.h>

using namespace featherstream;

#define MODE_DATA    0
#define MODE_HEADER  1
#define MODE_DISCARD 2

#define CMD_SET_8_BIT 0
#define CMD_SYSEX 255

OPCHandler::OPCHandler(
  Renderer &renderer,
  TwinkleAnimation &twinkleAnimation
): renderer(renderer), twinkleAnimation(twinkleAnimation) {
  this->mode = MODE_HEADER;
  this->numLEDs = this->nextNumLEDs = renderer.getLength();

  byte macBytes[6];
  WiFi.macAddress(macBytes);
  String macString = "";

  for (int i = 5; i >= 0; i--) {
    // macString += sprintf("%02X", macBytes[i]);
    // if (mac[i] < 16) {
    //   macString += "0";
    // }

    // macString += mac[i], HEX);
    macString += macBytes[i];
    if (i > 0) {
      macString += ":";
    }
  }

  this->deviceId = "feather:" + macString;
}

OPCHandler::~OPCHandler() {
}

bool OPCHandler::connect(uint8_t channel, const IPAddress &address, uint16_t port) {
  this->client = WiFiClient();

  if (this->client.connect(address, port)) {
    this->client.print("GET /devices/");
    this->client.print(this->getDeviceID());
    this->client.println("/opc HTTP/1.0");
    this->client.println();

    return true;
  } else {
    return false;
  }
}

void OPCHandler::disconnect() {
  this->client.stop();
}

bool OPCHandler::isConnected() {
  return this->client.connected();
}

const String &OPCHandler::getDeviceID() const {
  return this->deviceId;
}

bool OPCHandler::loop() {
  if (this->client.connected() && this->consecutiveSecondsWithoutFrames < 5) {
    /**
     * Processing logic copied in from lightship demo.
     */
    uint32_t t, seconds;
    int16_t  a, bytesPending;

    // DITHER-AND-RECEIVE LOOP STARTS HERE -------------------------------

    // // Interpolation weight (0-255) is the ratio of the time since last
    // // frame arrived to the prior two frames' interval.
    // t                   = micros();          // Current time
    // timeSinceFrameStart = t - this->lastFrameTime; // Elapsed since data recv'd
    // w                   = (timeSinceFrameStart >= this->timeBetweenFrames) ? 255 :
    //   (255L * timeSinceFrameStart / this->timeBetweenFrames);

    t = micros();
    this->renderer.render();
    this->updates++;

    // Show approximate updates-per-second
    if((seconds = (t / 1000000)) != this->priorSeconds) { // 1 sec elapsed?
      Serial.print("OPC handler: ");
      Serial.print(this->updates);
      Serial.println(" updates/sec");
      Serial.print("OPC handler: ");
      Serial.print(this->commits);
      Serial.println(" frames/sec");
      this->priorSeconds = seconds;
      this->updates      = 0; // Reset counter

      if (this->commits == 0) {
        this->consecutiveSecondsWithoutFrames++;

      } else {
        this->consecutiveSecondsWithoutFrames = 0;
      }
      this->commits      = 0;
    }

    // Process up to 1/2 of pending data on stream.  Rather than waiting
    // for full packets to arrive, this interleaves Stream I/O with LED
    // dithering so the latter doesn't get too 'stuttery.'  It DOES
    // however limit the potential throughput; 256 LEDs seems fine at
    // 60 FPS, but with 512 you may need to limit it to 30 FPS.
    bytesPending = this->client.available();
    if(bytesPending) {  // Any incoming data?
      bytesPending = (bytesPending + 1) / 2; // Handle a fraction of it
      uint8_t *rgbBuf = this->renderer.getRGBBuffer();

      uint16_t maxLength = this->renderer.getLength() * 3;

      do {
        if(this->mode == MODE_DATA) { // Receiving pixel data, most likely case
          // Read size mustn't exceed remaining pixel payload size or pixel
          // buffer size. This avoids some ugly cases like the next pixel
          // header appearing mid-buffer, which would require nasty memmoves
          // and stuff.  We'll read some now and pick up the rest on the
          // next pass through.
          if(bytesPending > this->bytesToRead) bytesPending = this->bytesToRead;
          if(bytesPending > maxLength) bytesPending = maxLength;
          if((a = this->client.read(&rgbBuf[this->bytesRead],
                              bytesPending)) > 0) {
            bytesPending -= a;
            this->bytesToRead  -= a;
            if(this->bytesToRead <= 0) { // End of pixel payload?
              if (this->cmd == CMD_SET_8_BIT) {
                this->renderer.commit();
                this->commits++;
                this->numLEDs       = this->nextNumLEDs;
              } else if (this->cmd == CMD_SYSEX) {
                if (this->dataSize < 2) {
                  Serial.println("Sysex command payload size too small, ignoring...");
                } else {
                  // Read a little-endian command ID, see
                  // https://forum.arduino.cc/index.php?topic=508999.0.
                  // uint16_t sysexCmd = rgbBuf[0] << 8 | rgbBuf[1];
                  uint16_t sysexCmd = *(uint16_t *)rgbBuf;

                  Serial.print("Got sysex command: ");
                  Serial.println(sysexCmd);

                  if (sysexCmd == 6) { // Change offline animation color.
                    if (this->dataSize == 6) {
                      uint8_t colorIndex = rgbBuf[2], r = rgbBuf[3], g = rgbBuf[4], b = rgbBuf[5];
                      Serial.print("Setting offline animation color ");
                      Serial.print(colorIndex);
                      Serial.print(" to R");
                      Serial.print(r);
                      Serial.print(" G");
                      Serial.print(g);
                      Serial.print(" B");
                      Serial.println(b);
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

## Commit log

2019-05-09 Initial work on vidopc -> frameplayer migration with fundamental API changes
2019-05-20 Working new version of frameplayer.
2019-05-26 Switch to string channel names
2019-05-26 Add sample wireless config and initial ansible boilerplate
2019-06-15 Add network switcher script template
2019-06-16 Cleaner LED rendering
2019-06-25 More useful LED blinks
2019-06-25 Treat no-frames-received as a disconnect from OPC
2019-06-25 Switch to more sensible directory structure
2019-06-27 Connected devices display
    - Track connected devices in server-side application state
    - Save connected devices along with their configured channel
    - Add endpoints for updating and forgetting connected devices
    - Link up all of the above in the web UI
2019-06-27 UI tweaks, set up functional web server on device
2019-07-02 Fixes for offline animation
    [Renderer.cpp, main.cpp]
2019-07-04 Command and structure for building media, work on OPC switching
2019-07-04 Set up media switching
2019-07-08 Add support for channel selection, fix a rendering bug
    [Renderer.cpp]
2019-07-08 Add color configuration logic on server, move brightness transformation to the device endpoint
2019-07-09 Working color picker, lots of fixes
    [OPCHandler.cpp, main.cpp]
2019-07-12 Initial work on boxes
    [feather_box.scad, nut_holder.scad, outer_box.scad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]
2019-07-15 First pass at pi box
    [RaspberryPiZeroW.STL, SuperBoost1000C.stl, feather_box.scad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]
2019-07-15 Add instructions for feather assembly
    [pi_box.scad, pi_box_fadecandy.scad]
2019-07-15 Add endcap
    [endcap.scad]
2019-07-15 README additions and reorg
    [dot_star_endcap.scad]
2019-07-16 Pi box next iteration
    [pi_box.scad]
2019-07-16 Pi box close to functional
    [pi_box.scad, pi_box_fade_candy.scad, pi_box_fadecandy.scad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]
2019-07-17 Pi box iterations
    [outer_box.scad, pi_box.scad]
2019-07-17 More pi box iterations to try and get the PowerBoost sitting right
    [pi_box.scad, power_boost_1000c.scad]
2019-07-17 Work on fadecandy stuff before box separation
    [pi_box.scad]
2019-07-17 Make the pi USB port accessible
    [pi_box.scad, pi_zero_w.scad]
2019-07-17 Remove fadecandy references from main pi box, initial FC only box
    [fade_candy_box.scad, pi_box.scad, pi_box_fade_candy.scad]
2019-07-17 Lid and cleanup for FC box
    [fade_candy_box.scad]
2019-07-17 Tighter USB port on feather box
    [feather_box.scad]
2019-07-17 Add inlay to feather box for USB accessibility
    [feather_box.scad]
2019-07-18 Add pinholes to pi box
    [pi_box.scad]
2019-07-18 Add pinhole to feather box
    [feather_box.scad, pi_box.scad]
2019-07-21 Set up listeners for rotary encoder input
2019-07-21 Cleanup on boxes
    [fade_candy_box.scad, feather_box.scad, pi_box.scad]
2019-07-22 Pinhole positioning tweaks, add LED pinhole to pi box
    [feather_box.scad, pi_box.scad]
2019-07-22 Blink LED according to current mode
2019-07-23 Initial pass at NeoPixel endcap
    [neo_pixel_endcap.scad]
2019-07-23 Feather assembly README update
2019-07-23 FadeCandy box mostly functional
    [fade_candy_box.scad]
2019-07-23 More Pi assembly instructions
2019-07-23 Tweak NeoPixel end cap cable diameter
    [neo_pixel_endcap.scad]
2019-08-03 Tons of stuff (#1)
    * WIP for on-pi ffmpeg processing
    * Initial structure for adding media files on the fly
    * Work on onboard media compilation
    * Media compilation wtihin JS working
    * Add a bit of extra space at the back fo the FC box
    * Tweak NeoPixel endcap cable radius
    * Add side walls to PowerBoost tower
    * Work on fcrelay command
    * Update README
    * First pass at flipped pi box
    * Use button presses instead of turns to select mode
    * Add default animation
    * Add command to generate frameplayer config, add some layout conf
    * Clean up old fpl files when new ones are detected
    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
    [fade_candy_box.scad, neo_pixel_endcap.scad, pi_box.scad]
